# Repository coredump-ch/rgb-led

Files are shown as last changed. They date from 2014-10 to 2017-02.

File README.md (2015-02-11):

# RGB LED

An RGB LED board, originally developed in fall 2014 by coredump hackerspace in
Rapperswil, Switzerland for teaching kids (~10y) the basics of electronics.

## Version 1

The v1 consists of a potentiometer for each RGB color. The current is only
controlled by the potentiometers. Therefore not too many LEDs can be driven at
the same time.

In contrast to v2 the v1 is also missing a switch to turn on/off the power.

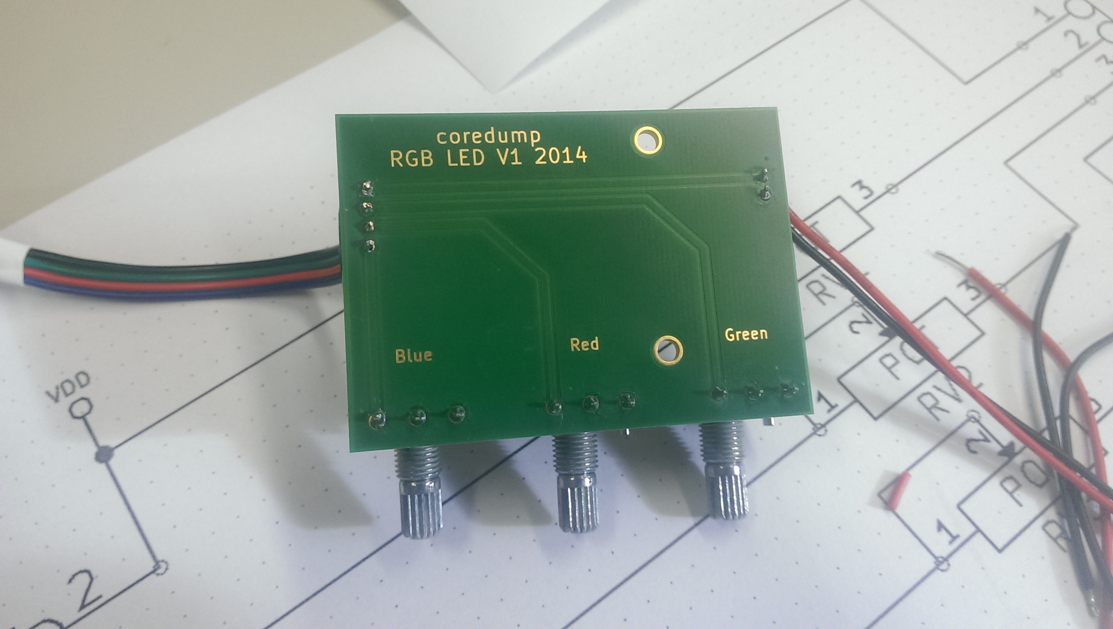
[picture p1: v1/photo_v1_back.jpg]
foto v1


## Version 2

The v2 is more advanced and uses an Arduino Nano as controller. The arduino
controls the RGB LEDs' brightness through PWM. The LEDs are switched with three
MOSFETs. This enables the control of more LEDs at the same time.

Project description is here: http://www.hackster.io/2460/arduino-controlled-rgb-led-strip

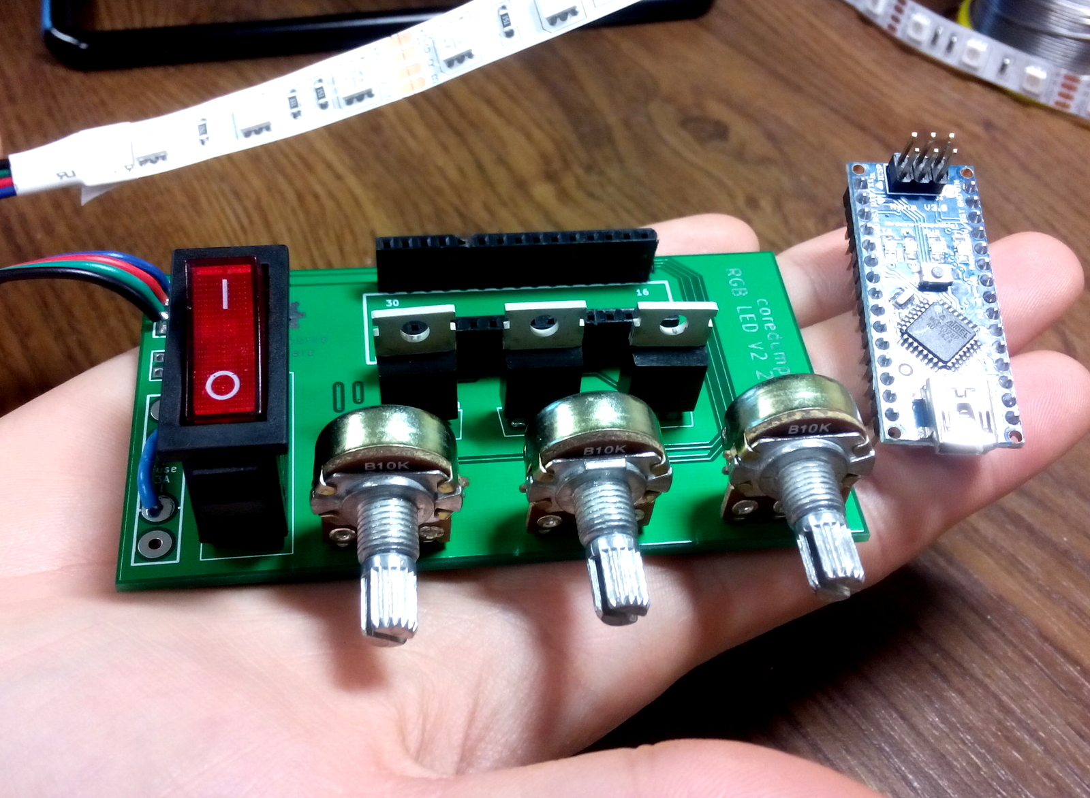
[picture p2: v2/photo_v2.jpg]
foto v2

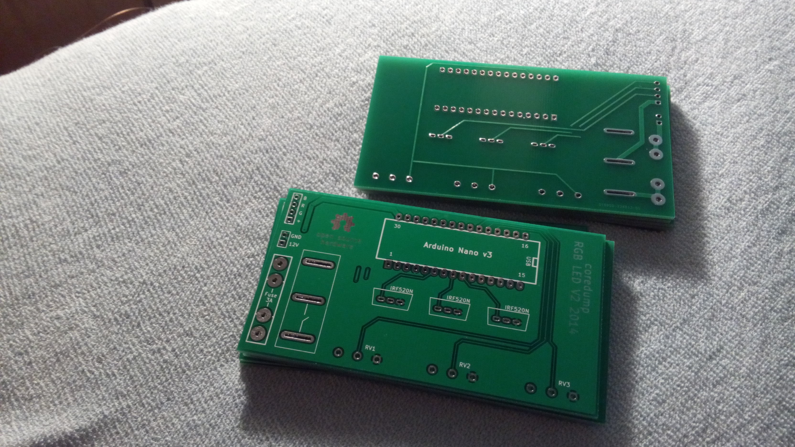
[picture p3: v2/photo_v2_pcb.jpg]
foto v2 pcb

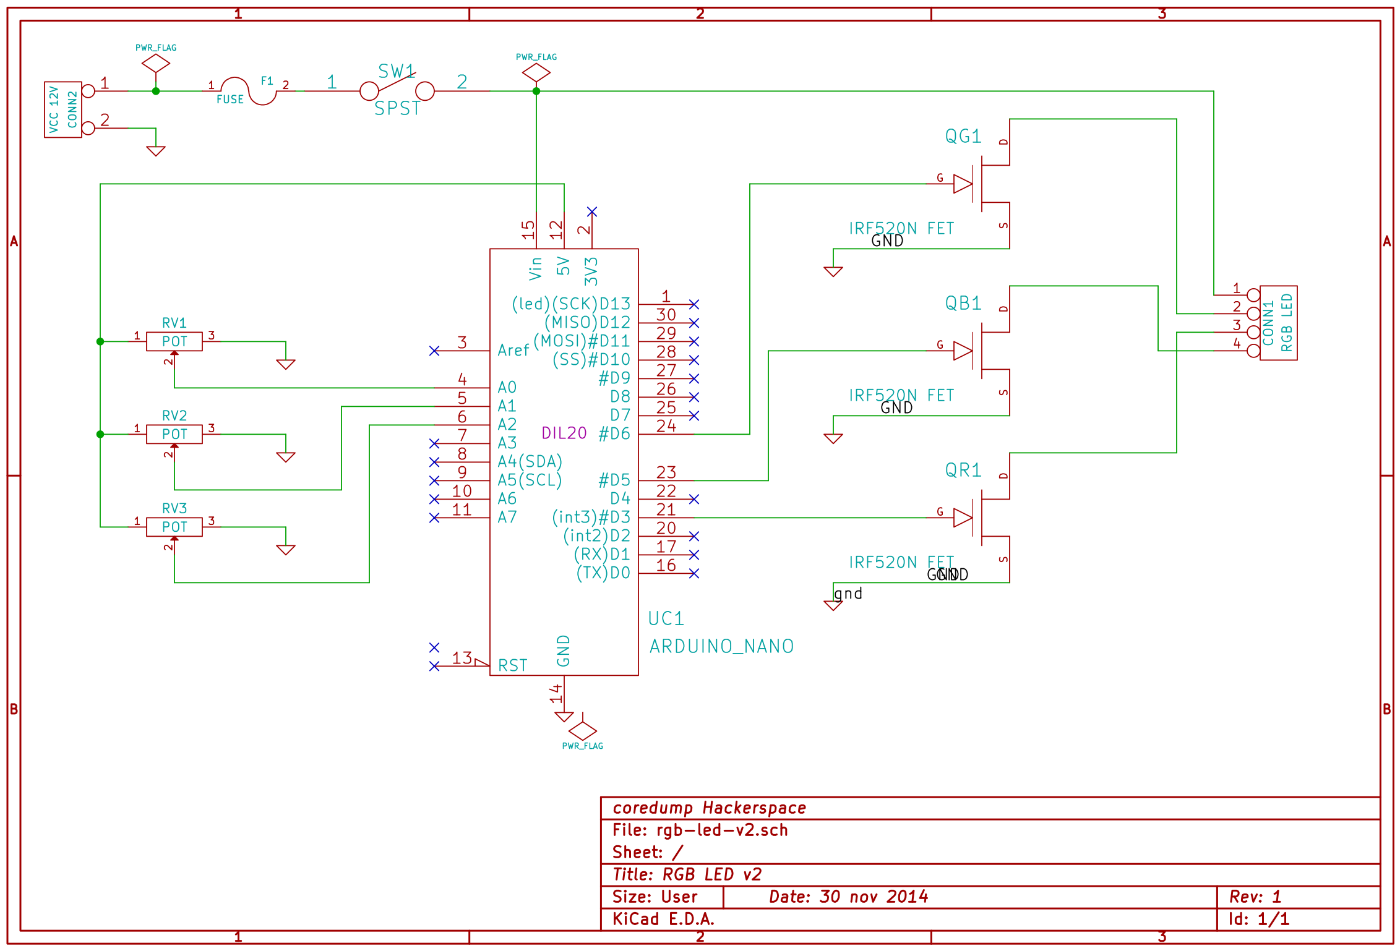
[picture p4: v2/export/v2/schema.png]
schema v2


## Licensing

See `LICENSE.md` file.

[v1-photo-back]: https://raw.githubusercontent.com/coredump-ch/rgb-led/master/v1/photo_v1_back.jpg
[v2-schema]: https://raw.githubusercontent.com/coredump-ch/rgb-led/master/v2/export/v2/schema.png
[v2-photo]: https://raw.githubusercontent.com/coredump-ch/rgb-led/master/v2/photo_v2.jpg
[v2-photo-pcb]: https://raw.githubusercontent.com/coredump-ch/rgb-led/master/v2/photo_v2_pcb.jpg

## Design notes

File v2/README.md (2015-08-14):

# Pinout

## LEDs

- Red: D3 / 1
- Green: D6 / 10
- Blue: D5 / 9

## Pots

- 1: A0 / 14
- 2: A1 / 15
- 3: A2 / 16

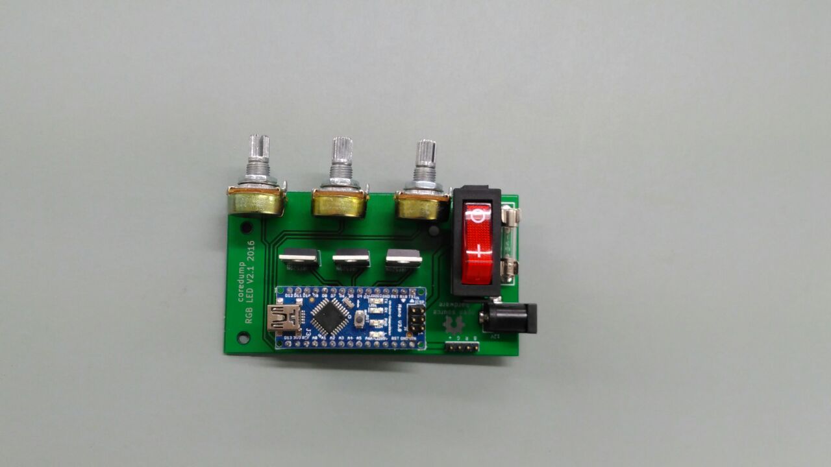
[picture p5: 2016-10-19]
v2/photo_v2.1_complete1.jpg

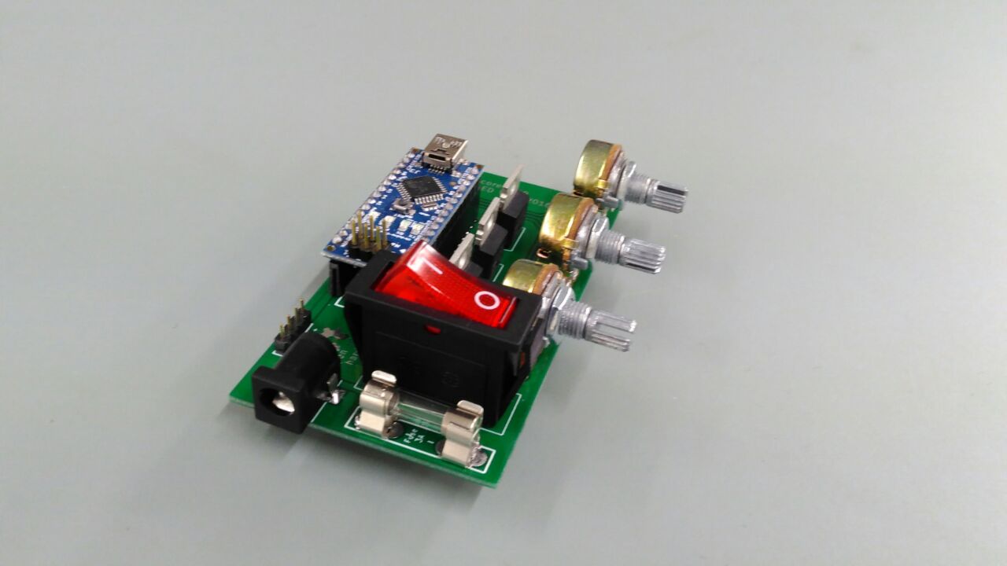
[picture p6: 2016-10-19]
v2/photo_v2.1_complete2.jpg

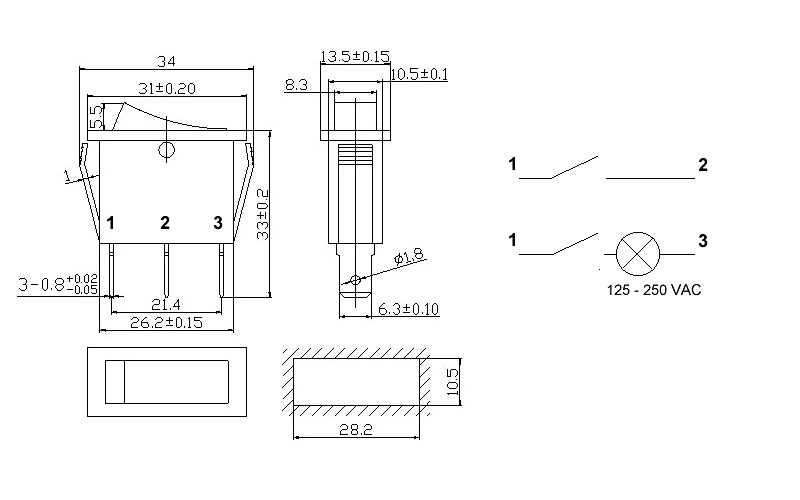
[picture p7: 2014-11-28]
kicad-library/kippschalter.gif

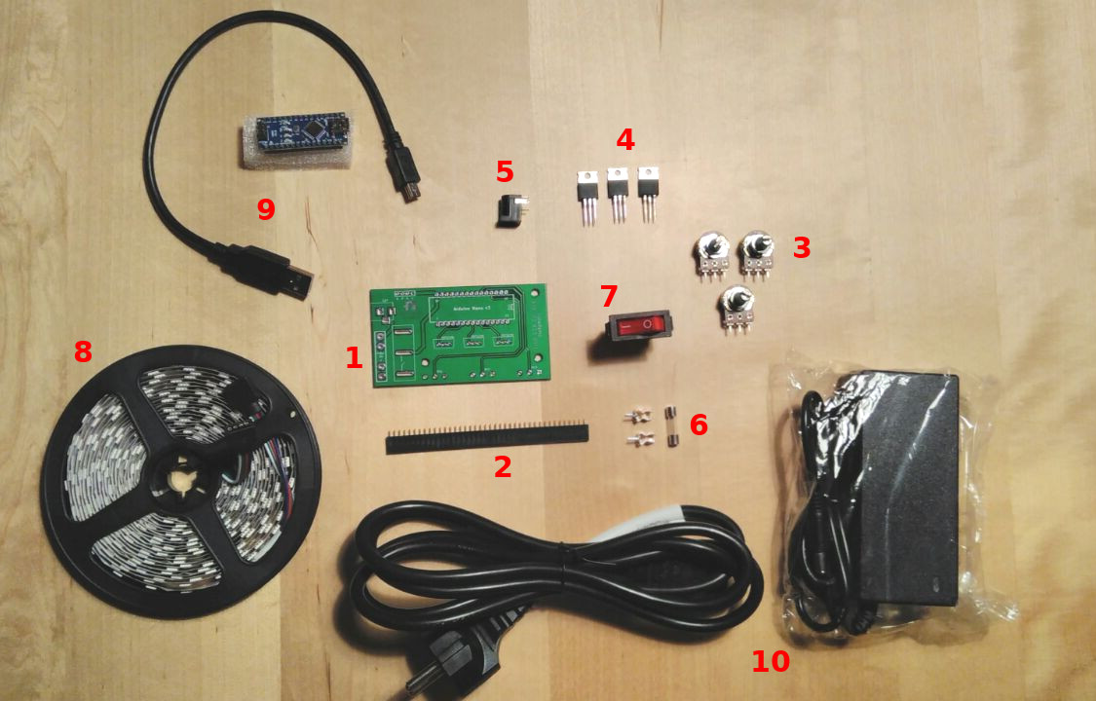
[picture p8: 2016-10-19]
v2/photo_v2.1_kit.jpg

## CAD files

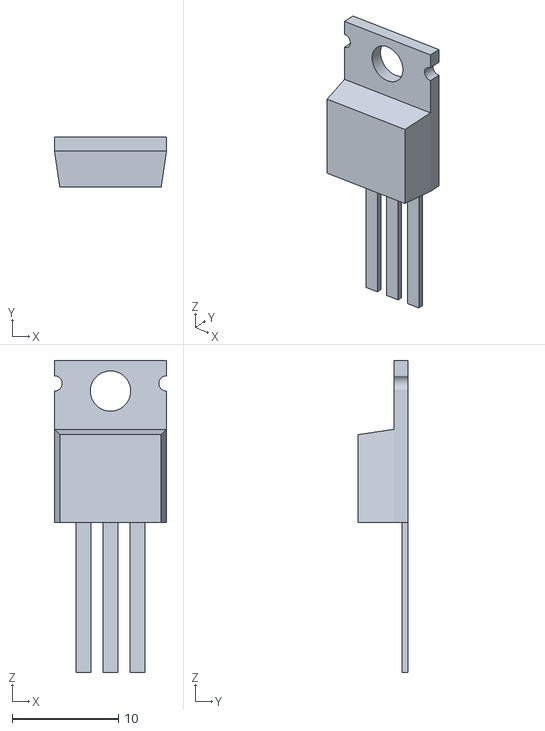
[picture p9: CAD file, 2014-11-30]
kicad-library/irf520n.fixed.stl
10.5 x 4.69 x 29.3

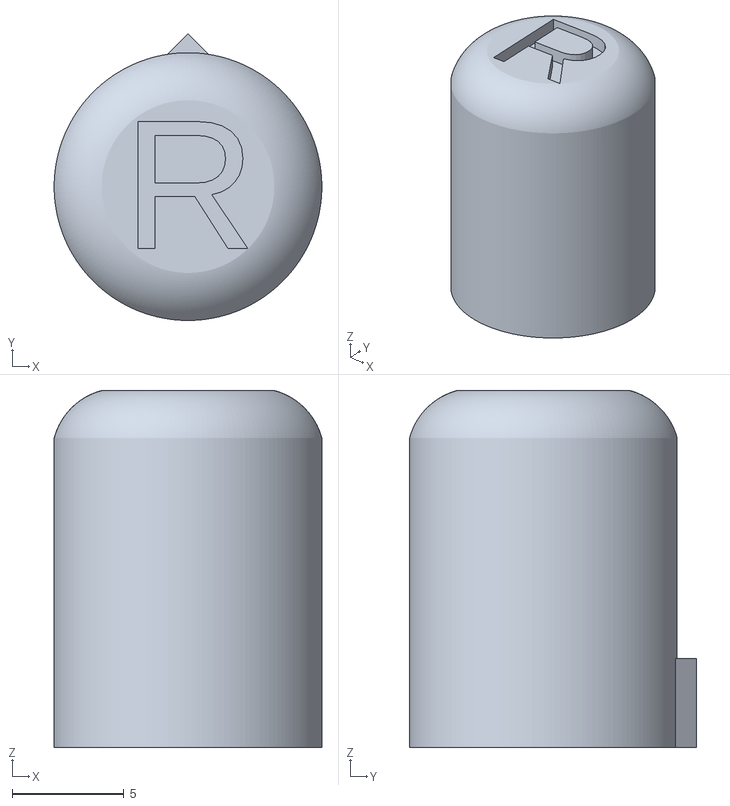
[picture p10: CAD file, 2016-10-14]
potknobs/knob-r-v3.stl
12.0 x 12.9 x 16.0

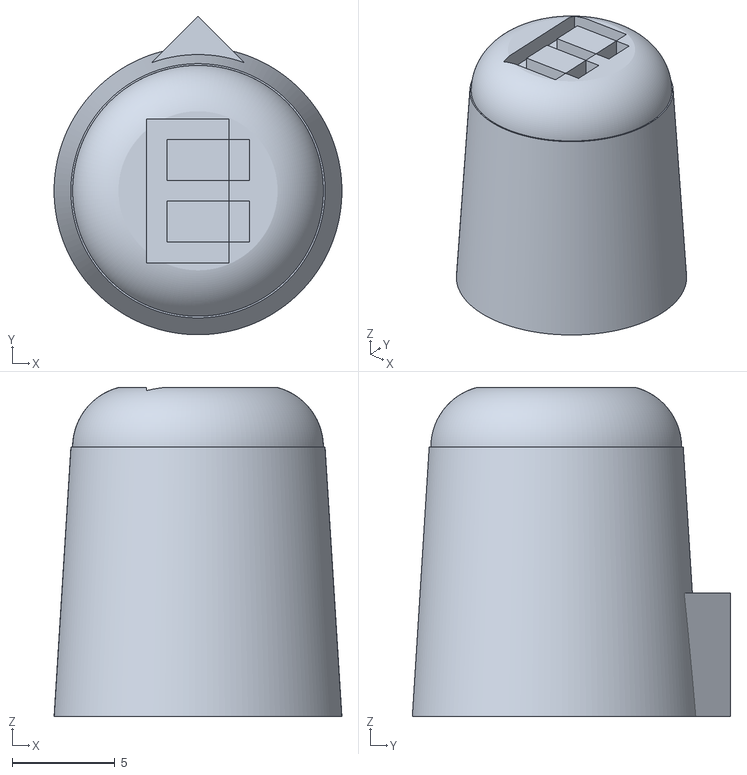
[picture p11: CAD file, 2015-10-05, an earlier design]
potknobs/knob-b-v2.stl
14.0 x 15.5 x 16.0

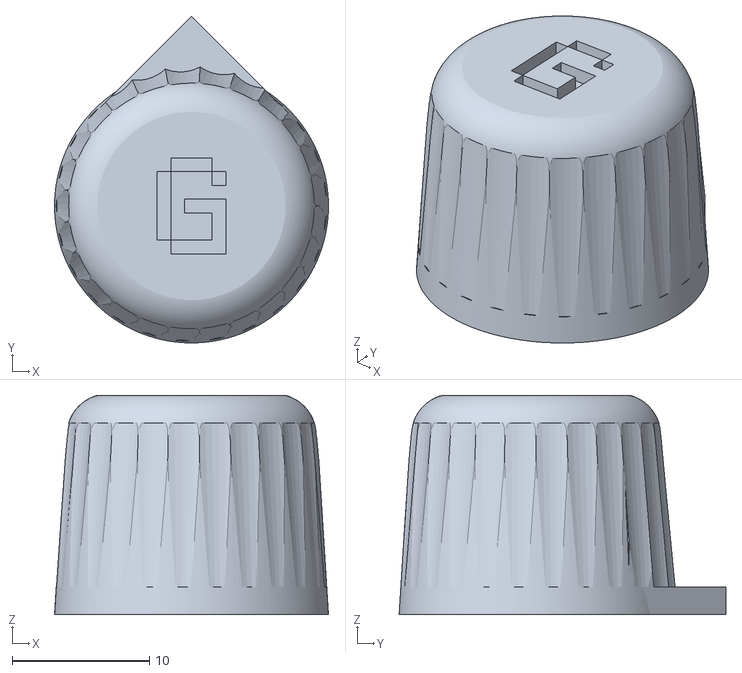
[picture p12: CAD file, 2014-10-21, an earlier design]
potknobs/knob-g.stl
20.0 x 23.9 x 16.0

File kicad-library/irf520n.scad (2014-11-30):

width = 10.54;
height2 = 15.24;
height1 = height2 - 6.47;
depth = 4.69;
indent = 0.5;
pin_length = 14.09;
metal_thickness = 1.32;

module metal() {
	small_circle_radius = 2.87 / 2 / 2;

	linear_extrude(height=metal_thickness) {
		difference() {
			square([10.54,height2]);
			translate([5.27,height2-2.87]) circle(3.78/2, $fn=200);
			translate([0,height2-2.87+small_circle_radius]) circle(small_circle_radius, $fn=200);
			translate([width,height2-2.87+small_circle_radius]) circle(small_circle_radius, $fn=200);
		};
	};
};

module casing() {
	polyhedron(
		points=[
			// Back
			[0,0,metal_thickness],[0,height1,metal_thickness],
			[width,height1,metal_thickness],[width,0,metal_thickness],
			// Front
			[0+indent,0,depth],[0+indent,height1-indent,depth],
			[width-indent,height1-indent,depth],[width-indent,0,depth]
		],
		faces=[[0,3,2,1],[4,5,6,7],[0,1,5,4],[1,2,6,5],[3,7,6,2],[0,4,7,3]]
	);
};

module pins() {
	pin_width = 1.4;
	center = (width / 2) - (pin_width / 2);
	distance = 2.54;

	translate([center-distance,-pin_length,0]) cube([pin_width,pin_length,0.55]);
	translate([center,-pin_length,0]) cube([pin_width,pin_length,0.55]);
	translate([center+distance,-pin_length,0]) cube([pin_width,pin_length,0.55]);
};

module everything() {
	union() {
		metal();
		casing();
		pins();
	};
};


rotate(a=[90,0,0]) everything();

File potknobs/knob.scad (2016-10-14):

/*

Parametric Potentiometer Knob Generator
version 2.0

2012 Steve Cooley
2014 Danilo Bargen

Parametric potentiometer knob generator by steve cooley is licensed under a
Creative Commons Attribution-NonCommercial-ShareAlike 3.0 Unported License.
Based on a work at sc-fa.com. Permissions beyond the scope of this license may
be available at http://sc-fa.com/blog/contact.

View terms of the license here:
http://creativecommons.org/licenses/by-nc-sa/3.0/


Version history
---------------

1.0 2012-03-?? initial release.
1.1 2012-04-12 fixed the arrow indicator code to be more robust and easier to adjust parameters for.
2.0 2014-09-17 updated the code
3.0 2016-10-14 replace custom text module with text() function and make knobs thinner


*/

//
//
// Physical attributes, basic
//
//

knob_radius_top = 6;
knob_radius_bottom = 6;
knob_height = 16;
knob_smoothness = 150;

shaft_radius = 3.16;
shaft_height = 13;
shaft_smoothness = 20;

shaft_is_flatted = false;
flat_size_adjustment = -0.0;
// you won't need to mess with this. less than 5 makes it disappear. you can, however,
// set the adjustment to be a negative decimal if you need a flat but not as big as the default. 
// go positive if you need a bigger flat
flat_size = 5 + flat_size_adjustment;

// some potentiometers need to have their knobs affixed with a set screw.
set_screw = false;
set_screw_radius = 1.5;
set_screw_depth = 9;
set_screw_height = 4;
quality_of_set_screw = 20;

//
// 
// Decorations
//
//

//
// top edge smoothing
// thanks to http://www.iheartrobotics.com/ for the articles!
//

smoothing = true;
smoothing_radius = 3;             // tweak on this one, how much smoothing to apply
smooth = 150;                     // tweak on this one, Number of facets of rounding cylinder

ct = -0.1;                        // circle translate? not sure.
circle_radius = knob_radius_top;  // just match the top edge radius
circle_height = 1;                // actually.. I don't know what this does.
pad = 0.2;                        // Padding to maintain manifold

top_letter = "R";

//
// directional indicators
//

// this is a corner edge of a cube sticking out of the cylinder at the bottom
// you can use it instead of the arrow shaped cutout in the top if you like. Or both.

pointy_external_indicator = true;
pointy_external_indicator_height = 4;
pointy_external_indicator_pokey_outey_ness = 0.05; // 
pokey_outey_value = pointy_external_indicator_pokey_outey_ness - 1 - pad;
pokey_outey = [pokey_outey_value, pokey_outey_value,0];

// there's an arrow shaped hole you can have. There aren't a lot of controls for this.
// please feel free to improve on this script here.

arrow_indicator = false;
arrow_indicator_scale = 1.3;
arrow_indicator_translate = [0,1,16];
arrow_scale_head = 1.5;
arrow_scale_shaft = 1;

//
// indentations
//

// for spherical indentations, set the quantity, quality, size, and adjust the placement
indentations_sphere = false;
sphere_number_of_indentations = 12;
sphere_quality_of_indentations = 4;
size_of_sphere_indentations = 4;
// the first number in this set moves the spheres in or out. smaller is closer to the middle
// the second number in this set moves the spheres left or right
// the third number in this set moves the speheres up or down
translation_of_sphere_indentations = [10,0,15];
// in case you are using an odd number of indentations, you way want to adjust the starting angle
// so that they align to the front or set screw locations.
sphere_starting_rotation = 90;

// for cylinder indentations, set quantity, quality, radius, height, and placement
indentations_cylinder = false;
cylinder_number_of_indentations = 25;
cylinder_quality_of_indentations = 50;
radius_of_cylinder_indentations_top = 4;
radius_of_cylinder_indentations_bottom = 3;
height_of_cylinder_indentations = 12;
translation_of_cylinder_indentations = [0,8,-8];
cylinder_starting_rotation = -33.3;

// these are some setup variables... you probably won't need to mess with them.
negative_knob_radius = knob_radius_bottom*-1;


inner_bar = true;
inner_bar_thickness = 1;
inner_bar_height = shaft_height - 3;
inner_bar_length = shaft_radius * 2 + 2;


// this is the main module. It calls the submodules.
make_the_knob();

module make_the_knob()
{
union() {
  difference() {
  difference()
    {
    difference()
      {
    
      difference() 
        {
        difference() 
          {
          
          union()
            {
            
            difference()
              {
              // main cylinder
              cylinder(r1=knob_radius_bottom,r2=knob_radius_top,h=knob_height, $fn=knob_smoothness);
              
              smoothing();        
    
              }
        
            external_direction_indicator();  

            }
          shaft_hole();
          }
          
        set_screw_hole();
        }
      
      arrow_indicator();
      indentations();
    }
  }
  letter();
  }
   inner_bar();
}
}

module smoothing() {
  // smoothing the top
  if(smoothing == true) {    
    translate([0,0,knob_height])
    rotate([180,0,0])
    difference() {
      rotate_extrude(convexity=10,  $fn = smooth)
      translate([circle_radius-ct-smoothing_radius+pad,ct-pad,0])
      square(smoothing_radius+pad,smoothing_radius+pad);

      rotate_extrude(convexity=10,  $fn = smooth)
      translate([circle_radius-ct-smoothing_radius,ct+smoothing_radius,0])
      circle(r=smoothing_radius,$fn=smooth);
      }  
  }
}

module external_direction_indicator() {
  if(pointy_external_indicator == true) {
    // outer pointy indicator
    rotate([0,0,45])
      translate(pokey_outey)
      // cube size of 8 minimum to point out
      cube(size=[knob_radius_bottom,knob_radius_bottom,pointy_external_indicator_height],center=false);
  }
}

module shaft_hole() {
        // shaft hole
        difference()
          {
          
          // round shaft hole
          translate([ 0, 0, -1 ]) 
          cylinder(r=shaft_radius,h=shaft_height, $fn=shaft_smoothness);
          
          if(shaft_is_flatted == true)
            {
            // D shaft shape for shaft cutout
            rotate( [0,0,90]) 
            translate([-7.5,-5,0]) 
            cube(size=[flat_size,10,13],center=false);
            }
          }
}


module set_screw_hole() {

      if(set_screw == true)
        {
        // set screw hole
        rotate ([90,0,0])
        translate([ 0, set_screw_height, 1 ])
        cylinder(r=set_screw_radius,h=set_screw_depth, $fn=quality_of_set_screw);
        }
}

module arrow_indicator() {
    if(arrow_indicator == true)
      {
      translate(arrow_indicator_translate)
      // begin arrow top cutout
      // translate([(knob_radius/2),knob_height,knob_height])
      rotate([90,0,45])
      scale([arrow_indicator_scale*.3,arrow_indicator_scale*.3,arrow_indicator_scale*.3])
      union()
        {        
        rotate([90,45,0])
        scale([arrow_scale_head,arrow_scale_head,1])
        cylinder(r=8, h=10, $fn=3, center=true);
        rotate([90,45,0])
        translate([-10,0,0])
        scale([arrow_scale_shaft,arrow_scale_shaft,1])
        cube(size=[15,10,10],center=true);
        }
      }
}

module indentations() {

if(indentations_sphere == true)
      {
      for (z = [0:sphere_number_of_indentations]) 
        {
        rotate([0,0,sphere_starting_rotation+((360/sphere_number_of_indentations)*z)])
        translate(translation_of_sphere_indentations)
        sphere(size_of_sphere_indentations, $fn=sphere_quality_of_indentations); 
        }
      }
if(indentations_cylinder == true)
      {
      for (z = [0:cylinder_number_of_indentations]) 
        {
        rotate([0,0,cylinder_starting_rotation+((360/cylinder_number_of_indentations)*z)])
        
        translate([negative_knob_radius,0,knob_height])
        translate(translation_of_cylinder_indentations)
        cylinder(r1=radius_of_cylinder_indentations_bottom, r2=radius_of_cylinder_indentations_top, h=height_of_cylinder_indentations, center=true, $fn=cylinder_quality_of_indentations); 
        }
      }
    }

module inner_bar() {
  if (inner_bar == true) {
    translate([-inner_bar_length/2,-inner_bar_thickness/2,shaft_height-inner_bar_height]) {
      cube([inner_bar_length,inner_bar_thickness,inner_bar_height]);
    }
  }
}

module letter() {
  translate([0,0,knob_height-0.7999])
    linear_extrude(0.8)
    text(top_letter, size=6, valign="center", halign="center");
}

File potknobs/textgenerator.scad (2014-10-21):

/*

OpenSCAD 3D Text Generator

http://www.thingiverse.com/thing:59817/

CC BY-SA Phil Greenland.
https://creativecommons.org/licenses/by-sa/3.0/

*/

//Draw text
scale([4,4,4]) drawtext("Hello World!");

//Draw character set
//scale([2,2,2]) drawtext(" !\"#$%&'()*+,-./0123456789:;<=>?@ABCDEFGHIJKLMNOPQRSTUVWXYZ[\\]^_`abcdefghijklmnopqrstuvwxyz{|}");

module drawtext(text) {
	//Characters
	chars = " !\"#$%&'()*+,-./0123456789:;<=>?@ABCDEFGHIJKLMNOPQRSTUVWXYZ[\\]^_`abcdefghijklmnopqrstuvwxyz{|}";

	//Chracter table defining 5x7 characters
	//Adapted from: http://www.geocities.com/dinceraydin/djlcdsim/chartable.js
	char_table = [ [ 0, 0, 0, 0, 0, 0, 0],
                  [ 4, 0, 4, 4, 4, 4, 4],
                  [ 0, 0, 0, 0,10,10,10],
                  [10,10,31,10,31,10,10],
                  [ 4,30, 5,14,20,15, 4],
                  [ 3,19, 8, 4, 2,25,24],
                  [13,18,21, 8,20,18,12],
                  [ 0, 0, 0, 0, 8, 4,12],
                  [ 2, 4, 8, 8, 8, 4, 2],
                  [ 8, 4, 2, 2, 2, 4, 8],
                  [ 0, 4,21,14,21, 4, 0],
                  [ 0, 4, 4,31, 4, 4, 0],
                  [ 8, 4,12, 0, 0, 0, 0],
                  [ 0, 0, 0,31, 0, 0, 0],
                  [12,12, 0, 0, 0, 0, 0],
                  [ 0,16, 8, 4, 2, 1, 0],
                  [14,17,25,21,19,17,14],
                  [14, 4, 4, 4, 4,12, 4],
                  [31, 8, 4, 2, 1,17,14],
                  [14,17, 1, 2, 4, 2,31],
                  [ 2, 2,31,18,10, 6, 2],
                  [14,17, 1, 1,30,16,31],
                  [14,17,17,30,16, 8, 6],
                  [ 8, 8, 8, 4, 2, 1,31],
                  [14,17,17,14,17,17,14],
                  [12, 2, 1,15,17,17,14],
                  [ 0,12,12, 0,12,12, 0],
                  [ 8, 4,12, 0,12,12, 0],
                  [ 2, 4, 8,16, 8, 4, 2],
                  [ 0, 0,31, 0,31, 0, 0],
                  [16, 8, 4, 2, 4, 8,16],
                  [ 4, 0, 4, 2, 1,17,14],
                  [14,21,21,13, 1,17,14],
                  [17,17,31,17,17,17,14],
                  [30,17,17,30,17,17,30],
                  [14,17,16,16,16,17,14],
                  [30,17,17,17,17,17,30],
                  [31,16,16,30,16,16,31],
                  [16,16,16,30,16,16,31],
                  [15,17,17,23,16,17,14],
                  [17,17,17,31,17,17,17],
                  [14, 4, 4, 4, 4, 4,14],
                  [12,18, 2, 2, 2, 2, 7],
                  [17,18,20,24,20,18,17],
                  [31,16,16,16,16,16,16],
                  [17,17,17,21,21,27,17],
                  [17,17,19,21,25,17,17],
                  [14,17,17,17,17,17,14],
                  [16,16,16,30,17,17,30],
                  [13,18,21,17,17,17,14],
                  [17,18,20,30,17,17,30],
                  [30, 1, 1,14,16,16,15],
                  [ 4, 4, 4, 4, 4, 4,31],
                  [14,17,17,17,17,17,17],
                  [ 4,10,17,17,17,17,17],
                  [10,21,21,21,17,17,17],
                  [17,17,10, 4,10,17,17],
                  [ 4, 4, 4,10,17,17,17],
                  [31,16, 8, 4, 2, 1,31],
                  [14, 8, 8, 8, 8, 8,14],
                  [ 0, 1, 2, 4, 8,16, 0],
                  [14, 2, 2, 2, 2, 2,14],
                  [ 0, 0, 0, 0,17,10, 4],
                  [31, 0, 0, 0, 0, 0, 0],
                  [ 0, 0, 0, 0, 2, 4, 8],
                  [15,17,15, 1,14, 0, 0],
                  [30,17,17,25,22,16,16],
                  [14,17,16,16,14, 0, 0],
                  [15,17,17,19,13, 1, 1],
                  [14,16,31,17,14, 0, 0],
                  [ 8, 8, 8,28, 8, 9, 6],
                  [14, 1,15,17,15, 0, 0],
                  [17,17,17,25,22,16,16],
                  [14, 4, 4, 4,12, 0, 4],
                  [12,18, 2, 2, 2, 6, 2],
                  [18,20,24,20,18,16,16],
                  [14, 4, 4, 4, 4, 4,12],
                  [17,17,21,21,26, 0, 0],
                  [17,17,17,25,22, 0, 0],
                  [14,17,17,17,14, 0, 0],
                  [16,16,30,17,30, 0, 0],
                  [ 1, 1,15,19,13, 0, 0],
                  [16,16,16,25,22, 0, 0],
                  [30, 1,14,16,15, 0, 0],
                  [ 6, 9, 8, 8,28, 8, 8],
                  [13,19,17,17,17, 0, 0],
                  [ 4,10,17,17,17, 0, 0],
                  [10,21,21,17,17, 0, 0],
                  [17,10, 4,10,17, 0, 0],
                  [14, 1,15,17,17, 0, 0],
                  [31, 8, 4, 2,31, 0, 0],
                  [ 2, 4, 4, 8, 4, 4, 2],
                  [ 4, 4, 4, 4, 4, 4, 4],
                  [ 8, 4, 4, 2, 4, 4, 8] ];

	//Binary decode table
	dec_table = [ "00000", "00001", "00010", "00011", "00100", "00101",
  	            "00110", "00111", "01000", "01001", "01010", "01011",
  	            "01100", "01101", "01110", "01111", "10000", "10001",
  	            "10010", "10011", "10100", "10101", "10110", "10111",
	            "11000", "11001", "11010", "11011", "11100", "11101",
	            "11110", "11111" ];

	//Process string one character at a time
	for(itext = [0:len(text)-1]) {
		//Convert character to index
		assign(ichar = search(text[itext],chars,1)[0]) {
			//Decode character - rows
			for(irow = [0:6]) {
				assign(val = dec_table[char_table[ichar][irow]]) {
					//Decode character - cols
					for(icol = [0:4]) {
						assign(bit = search(val[icol],"01",1)[0]) {
							if(bit) {
								//Output cube
								translate([icol + (6*itext), irow, 0])
									cube([1.0001,1.0001,1]);
							}
						}
					}
				}
			}
		}
	}
}

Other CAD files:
kicad-library/irf520n.stl
potknobs/knob-g-v3.stl
potknobs/knob-b-v3.stl
potknobs/knob-neutral-v3.stl
potknobs/knob-g-v2.stl
potknobs/knob-r-v2.stl
potknobs/knob-r.stl
potknobs/knob-b.stl

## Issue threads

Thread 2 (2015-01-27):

Add buttons and/or rotary encoder

dbrgn, 2015-01-27:
They can be used to step through different effects.

dbrgn, 2015-01-27:
They can be used to step through different effects.

dbrgn, 2015-08-24:
I think the best solution would be to add a single rotary encoder.

dns2utf8, 2016-03-07:
I would prefere a rotay encoder and two buttons.

dbrgn, 2016-03-07:
The other option is an ESP8266 and an app :)

dbrgn, 2016-08-11:
Something like this? http://mikroshop.ch/?gruppe=10&artikel=44 Has an integrated push-button.

Closed 2017-02-19.

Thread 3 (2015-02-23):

Mounting holes

dbrgn, 2015-02-23:

schmijos, 2015-02-24:
?

dbrgn, 2015-02-24:
Das PCB (v2.1) braucht noch mounting holes :) So wie hier, einfach professioneller:

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

schmijos, 2015-02-24:
Achso :-)

rnestler, 2015-02-24:
Wie geil :smile:

rnestler, 2016-09-21:
closed with #11

Closed 2016-09-21.

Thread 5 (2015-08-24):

Add power switch to v1 PCB

rnestler, 2015-08-24:
The simple v1 PCB should have a power switch nonetheless.

dbrgn, 2016-08-11:
Can probably be closed now right?

Closed 2016-08-11.

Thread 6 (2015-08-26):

v3: Add breakout pins

dbrgn, 2015-08-26:
That would be nice, wouldn't it? :) Not sure if it's easily possible with this PCB though.

dbrgn, 2016-08-11:
This would be nice-to-have for the v2.1 board.

Closed 2017-02-19.

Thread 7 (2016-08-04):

Holes for switch are a bit narrow

dbrgn, 2016-08-04:
Make them a tiny bit wider.

rnestler, 2016-08-24:
In x or y direction or both?

dbrgn, 2016-08-31:
Width (the shorter of the two axes). The length is OK.

Closed 2016-09-15.

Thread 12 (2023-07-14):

Arduino fried

Omega1806, 2023-07-14:
Hi, i tried the project.
Did the PCB's at pcbway, and started the project.
I just wanted the classic, potentiometer RGB controller.
First try, put the program with effects on the arduino.
After starting it, i couldn't connect to the board any more, or upload any code.
Secound try, bought another Arduino.
Test no.1: with 1m LED strip and 12v 2A power supply, SUCCESS! it worked.
Test no 2: swaped the 1m strip with 4m, same power supply. Arduino started smoking. Burned the 5v regulator on it.
Test no 3: swaped the Arduino board with a new one. after starting i got green colour flashing + no reaction on the potentiometers + Arduino started to heat up.

What could be the issue? i'm kind of runnin' out of ideas and money for this project (getting to expensive).

Please help!

Thanks 😄

PS: tested every soldering for shortcircuits. the tests from the secound arduino were made with a new pcb. and new components.

dbrgn, 2023-07-16:
Are you using the same components as in our v2 schema here? https://raw.githubusercontent.com/coredump-ch/rgb-led/master/v2/export/v2/schema.png (i.e. MOSFETs and not transistors, and an appropriate power supply and fuse?)

Omega1806, 2023-07-17:
Hi, Thanks for the answer!
The only thing that was different was that i didn't have a 6A power supply, just a 2A power supply. Wich worked just fine until i tried the 4m LED strip...After that the 5V regulator in the Arduino started smoking.
That i might fried it with the "too small power supply", i don't argue. What i don't understand is why doesn't it work with another Arduino. Are there other components fried? I messured the mosfets, everything seems fine.

dbrgn, 2023-07-17:
I don't quite understand how it could fry the Arduino. The LED strips are powered directly by the power supply, and the Arduino simply switches the MOSFETs on and off.

The only thing I could imagine based on the schematic is that the LED strips could try to source current from the Arduino's VIn pin if the power supply does not provide enough power. However, I assume that the Arduino prevents that.

(Maybe @rnestler has another idea...)

Omega1806, 2023-07-17:
the problem is why isn't it working after swiching the arduino?
i mean before switching the 1m strip with the 4m one, everything worked fine...
This is my third try with the project. At the first try, i loaded the program with effects, but i wanted just the simple one with the potentiometers, but i couldn't load any program on the Arduino, comunication error.
bought everything for the second try, worked just fine before i switched the 1m strip with the 4m one.
Now i buy a 6A power supply, new arduino, new mosfets, new potentiometers, everything, and try again...

Ps: this is for my son, he is 4 years old, and i have done a plexiglass, wallmounted "lego ninjago" sign, wich i planned to light up with LED strip, wich he can adjust via potentiometers, so he can learn to mix colours.

rnestler, 2023-07-20:
If the LEDs draw so much current, that the voltage of the 2A supply drops *below* 5V, current may start to flow in reverse for a short period. Then the Arduino may reset and thus turning the LEDs off, which will stabilize the the voltage again, but then will immediately drop again since the Arduino turns the LEDs on again. (This would explain the color flashing)

This oscillating may then break the power supply of the Arduino.

But this is a very hand wavy explanation :wink:

rnestler, 2023-07-20:
The only protection the board has is the fuse, which of course needs to be rated *below* the maximum current the power-supply can deliver, since otherwise it is useless.

Theoretically one could add a software monitoring of the 12V supply and go in a fail state if the voltage ever drops below 10V or something (but this is hard to achieve, since measuring the voltage that powers your device is hard and it would also need to react extremely fast to handle a quasi short circuit from too many LEDs)

dbrgn, 2023-07-20:
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

Ah yeah, that makes sense!

Omega1806, 2023-07-21:
Hi guys, thank you all for the feedback!
The LED strip says on the specs that it consumes 14,5 W per meter. I connected 4m.

I will try again next week with a new arduino and a 5-6A power supply and get back to you with the results.

Have a nice weekend!!

rnestler, 2023-07-21:
>  The LED strip says on the specs that it consumes 14,5 W per meter. I connected 4m.

With a Voltage of 12V this gives you 4.83A: `(14.5W/m * 4m) /12V = 4.833A`. So a 5-6A power supply should be sufficient.

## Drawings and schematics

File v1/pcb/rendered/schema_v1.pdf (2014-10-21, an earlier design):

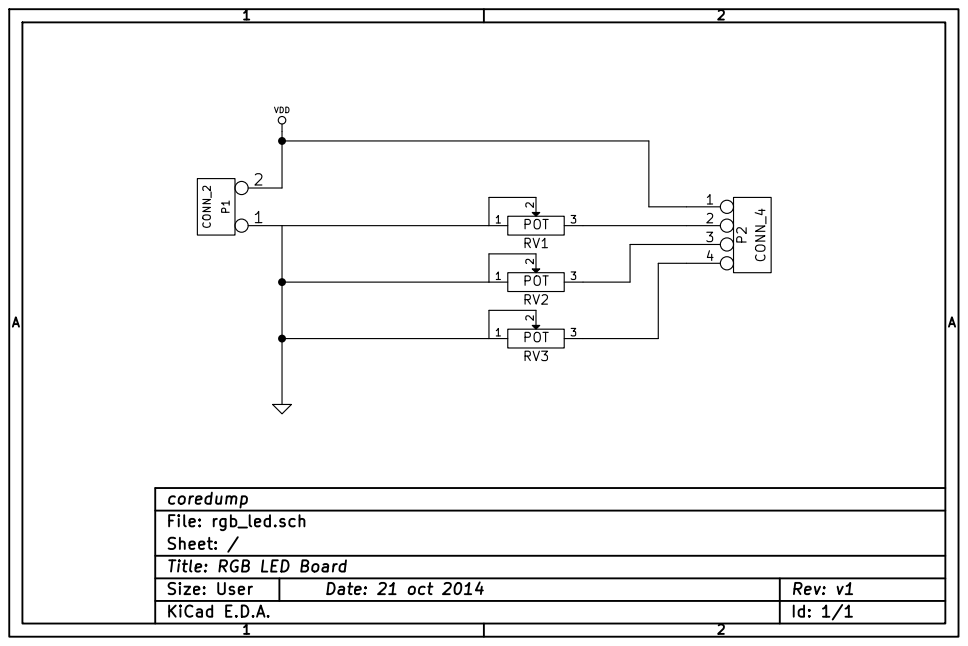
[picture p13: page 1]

coredump
File: rgb_led.sch
Sheet: /
Title: RGB LED Board

Size: User | Rev: v1

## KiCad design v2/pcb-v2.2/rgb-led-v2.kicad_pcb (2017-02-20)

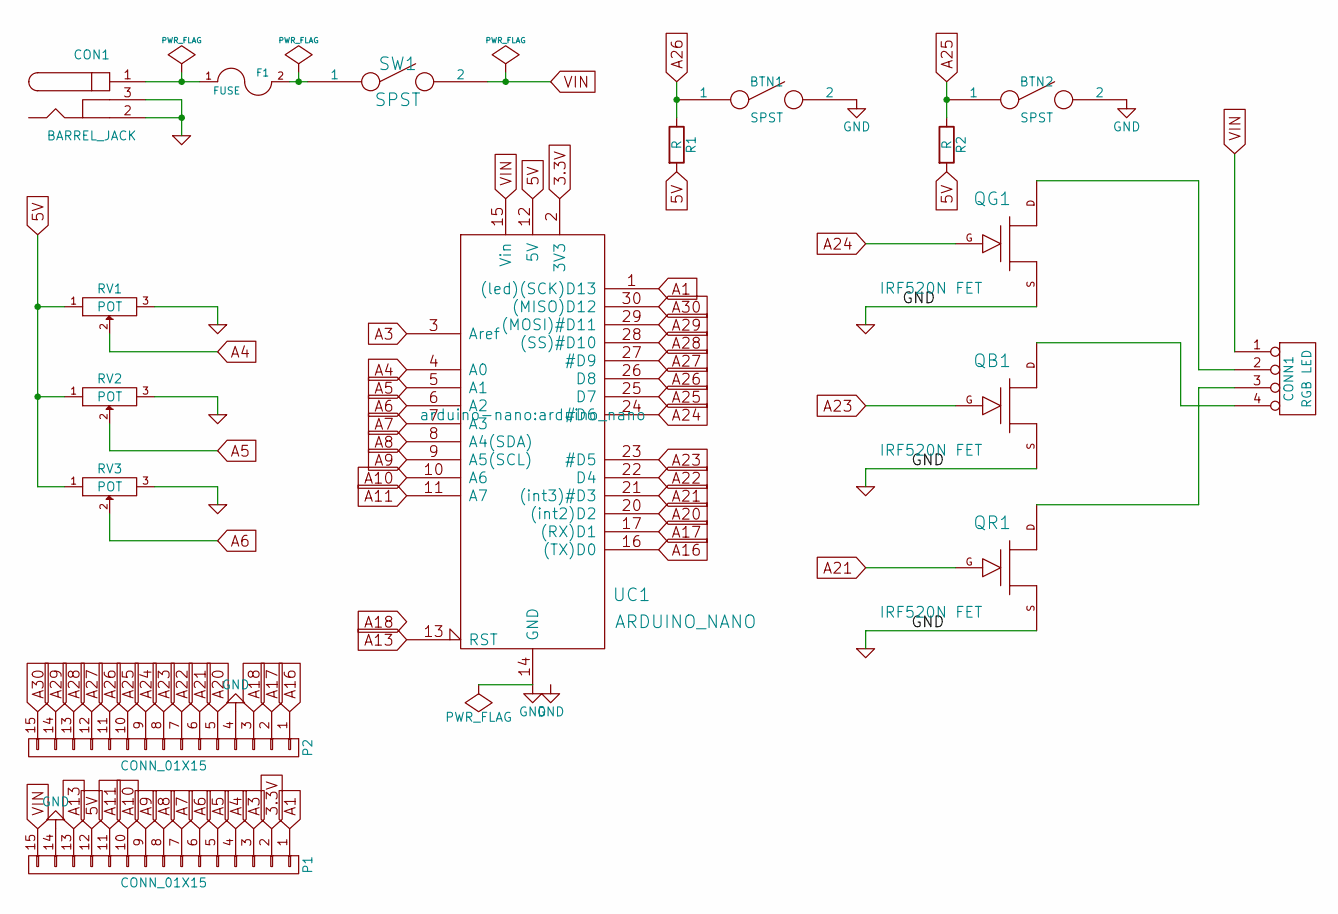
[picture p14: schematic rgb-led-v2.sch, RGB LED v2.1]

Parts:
BTN1, BTN2: SPST; PUSHBUTTON_TS044S
CON1: BARREL_JACK
CONN1: RGB LED; PIN_ARRAY_4x1_THICK
F1: FUSE; KCD3
P1, P2: CONN_01X15; Pin_Header_Straight_1x15_Pitch2.54mm
QB1: IRF520N FET; IRF520N
QG1: IRF520N FET; IRF520N
QR1: IRF520N FET; IRF520N
R1, R2: R; R_Axial_DIN0207_L6.3mm_D2.5mm_P10.16mm_Horizontal
RV1, RV2, RV3: POT; POT_3
SW1: SPST; Switch_SS-12F46
UC1: ARDUINO_NANO; arduino_nano

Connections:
3.3V: P1.2, UC1.2 (3V3)
5V: P1.12, R1.2, R2.2, RV1.1, RV2.1, RV3.1, UC1.12 (5V)
A1: P1.1, UC1.1 ((led)(SCK)D13)
A3: P1.3, UC1.3 (Aref)
A4: P1.4, RV1.2, UC1.4 (A0)
A5: P1.5, RV2.2, UC1.5 (A1)
A6: P1.6, RV3.2, UC1.6 (A2)
A7: P1.7, UC1.7 (A3)
A8: P1.8, UC1.8 (A4(SDA))
A9: P1.9, UC1.9 (A5(SCL))
A10: P1.10, UC1.10 (A6)
A11: P1.11, UC1.11 (A7)
A13: P1.13, UC1.13 (RST)
A16: P2.1, UC1.16 ((TX)D0)
A17: P2.2, UC1.17 ((RX)D1)
A18: P2.3, UC1.18 (RST)
A20: P2.5, UC1.20 ((int2)D2)
A21: P2.6, QR1.G, UC1.21 ((int3)#D3)
A22: P2.7, UC1.22 (D4)
A23: P2.8, QB1.G, UC1.23 (#D5)
A24: P2.9, QG1.G, UC1.24 (#D6)
A25: BTN2.1, P2.10, R2.1, UC1.25 (D7)
A26: BTN1.1, P2.11, R1.1, UC1.26 (D8)
A27: P2.12, UC1.27 (#D9)
A28: P2.13, UC1.28 ((SS)#D10)
A29: P2.14, UC1.29 ((MOSI)#D11)
A30: P2.15, UC1.30 ((MISO)D12)
GND: BTN1.2, BTN2.2, CON1.2, CON1.3, P1.14, P2.4, QB1.S, QG1.S, QR1.S, RV1.3, RV2.3, RV3.3, UC1.14 (GND), UC1.19 (GND)
unnamed: CON1.1, F1.1
unnamed: CONN1.2, QG1.D
unnamed: CONN1.3, QR1.D
unnamed: CONN1.4, QB1.D
unnamed: F1.2, SW1.1
VIN: CONN1.1, P1.15, SW1.2, UC1.15 (Vin)

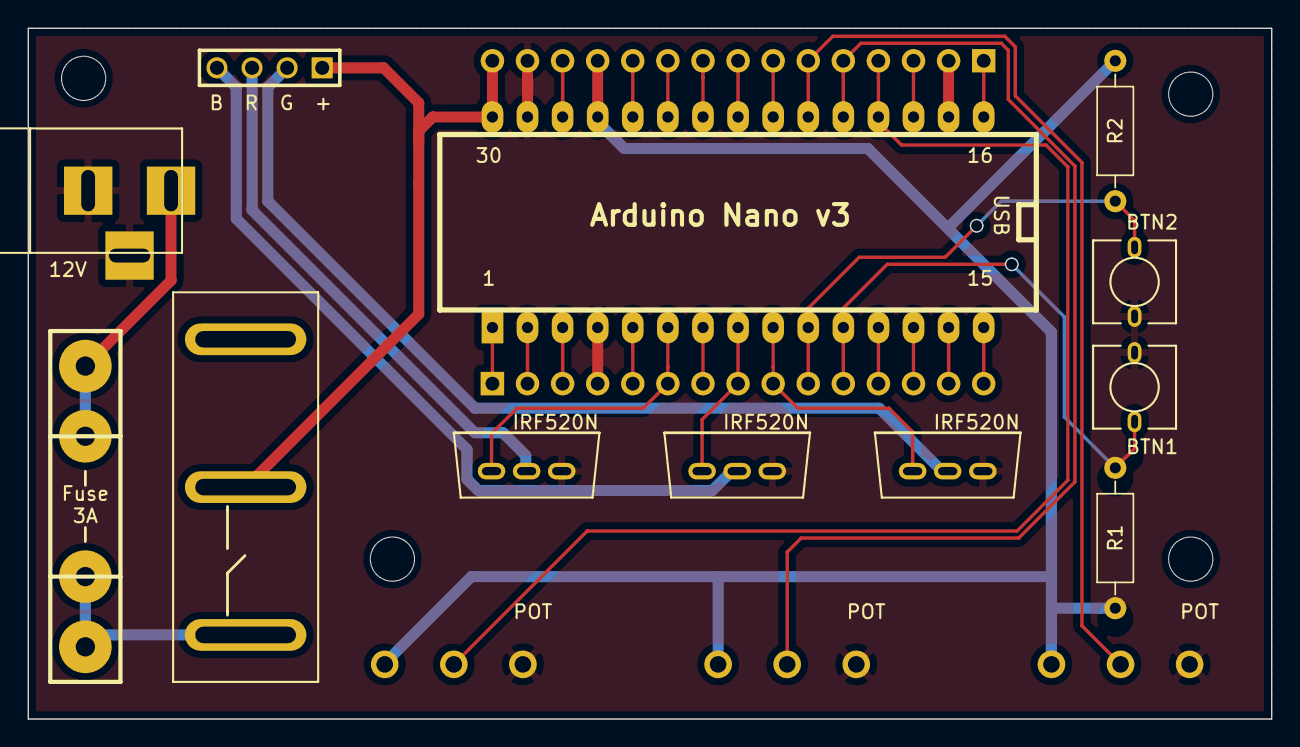
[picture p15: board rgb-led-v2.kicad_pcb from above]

Board: 2 copper layers, 90.0 x 50.0 mm, 17 parts (0 on the bottom side), 34 nets.

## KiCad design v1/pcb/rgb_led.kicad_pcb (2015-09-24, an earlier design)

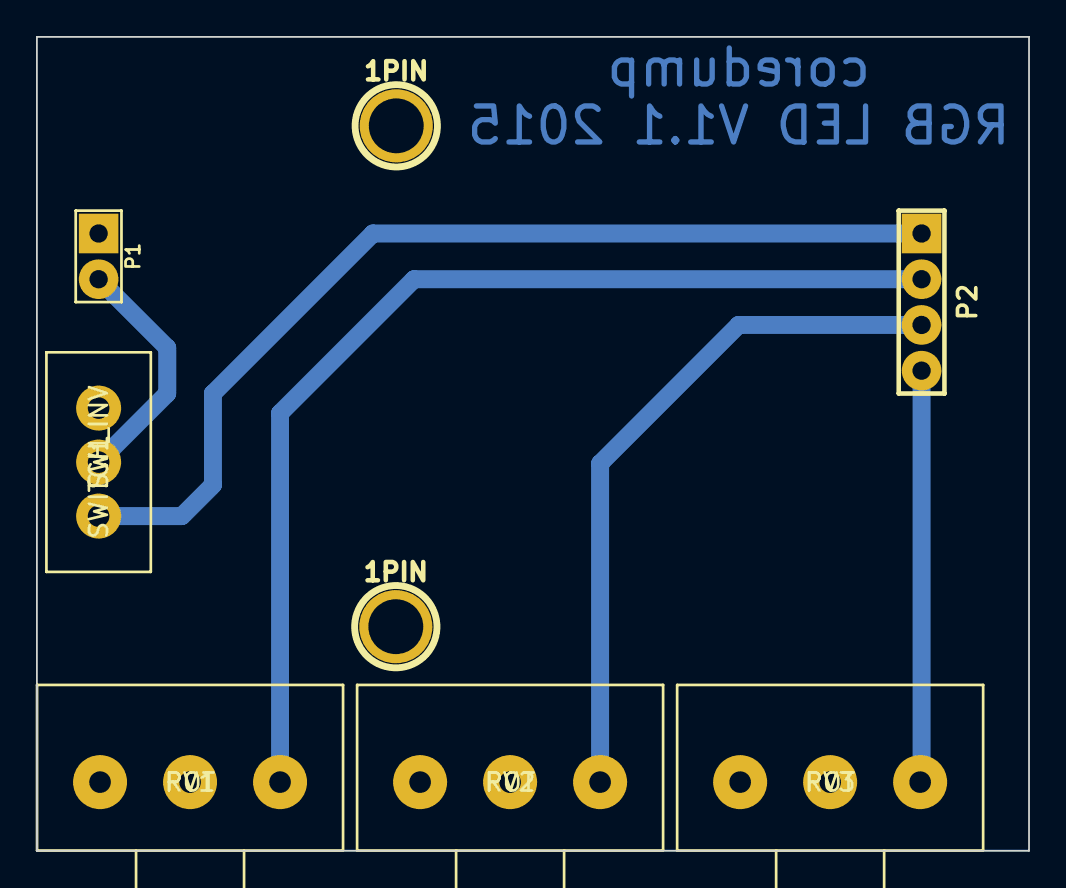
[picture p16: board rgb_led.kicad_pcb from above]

Board: 2 copper layers, 55.1 x 45.2 mm, 8 parts (0 on the bottom side), 6 nets.

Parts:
1PIN, 1PIN#2: P***; 1pin
P1: CONN_2; PIN_ARRAY_2X1_THICK
P2: CONN_4; PIN_ARRAY_4x1_THICK
RV1, RV2, RV3: POT; POT_3_THICK
SW1: SWITCH_INV; Switch_SS-12F46

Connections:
GND: P1.1, RV1.1, RV1.2, RV2.1, RV2.2, RV3.1, RV3.2
unnamed: P2.4, RV3.3
unnamed: P2.3, RV2.3
unnamed: P2.2, RV1.3
unnamed: P2.1, SW1.1
VDD: P1.2, SW1.2

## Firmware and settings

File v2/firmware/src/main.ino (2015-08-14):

/**
 * Main entry point for RGB LED controller.
 *
 * Copyright (c) 2014--2015 Coredump Rapperswil
 *
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
 * THE SOFTWARE IS PROVIDED “AS IS”, WITHOUT WARRANTY OF ANY KIND, EXPRESS OR
 * IMPLIED, INCLUDING BUT NOT LIMITED TO THE WARRANTIES OF MERCHANTABILITY,
 * FITNESS FOR A PARTICULAR PURPOSE AND NONINFRINGEMENT. IN NO EVENT SHALL THE
 * AUTHORS OR COPYRIGHT HOLDERS BE LIABLE FOR ANY CLAIM, DAMAGES OR OTHER
 * LIABILITY, WHETHER IN AN ACTION OF CONTRACT, TORT OR OTHERWISE, ARISING
 * FROM, OUT OF OR IN CONNECTION WITH THE SOFTWARE OR THE USE OR OTHER DEALINGS
 * IN THE SOFTWARE.
 */

// Get pin definitions
#include "pins.h"

// Include effects
#include "effects/colorwheel.h"
#include "effects/rgb_control.h"


// List of available effects
enum Effect {
    Colorwheel,
    RGBControl,
};

// Choose your effect
static const Effect effect = Colorwheel;


// Initialize GPIO pins
void setup() {
    // Set LED pins as output
    pinMode(LED_R, OUTPUT);
    pinMode(LED_G, OUTPUT);
    pinMode(LED_B, OUTPUT);

    // Set pot pins as input
    pinMode(POT_1, INPUT);
    pinMode(POT_2, INPUT);
    pinMode(POT_3, INPUT);
}


// Main loop
void loop() {

    switch (effect) {
        case Colorwheel:
            effect_colorwheel(); 
            break;
        case RGBControl:
            effect_rgb_control(); 
            break;
    }

}

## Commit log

2014-10-21 Added pcb design
    [rgb_led.kicad_pcb, rgb_led.sch, rgb_led_theorie.sch]
2014-10-21 Added potentiometer knobs
    [knob-b.stl, knob-g.stl, knob-r.stl]
2014-10-21 Smaller page config for schema
    [rgb_led.sch]
2014-10-21 Added potknob sources
    [knob.scad, textgenerator.scad]
2014-10-30 Added v2.0
    [rgb-led.fzz]
2014-10-30 Version 2.1
    [rgb-led.fzz]
2014-10-30 Version 2.2
    [rgb-led.fzz]
2014-11-01 Small tweaks on v2 project
    [rgb-led.fzz]
2014-11-27 Moved around folders
    [rgb_led.kicad_pcb, rgb_led.sch, rgb_led_theorie.sch]
2014-11-27 Started kicad version of v2
    [rgb-led-v2.sch, rgb-led.fzz]
2014-11-27 Continued work on v2
    [rgb-led-v2.sch, rgb-led.fzz]
2014-11-29 [library] Added IRF520 FET and KCD3 Switch
2014-11-29 [v2] Finished netlist assignment
    [rgb-led-v2.sch]
2014-11-29 [v2] Started work on PCB layout
    [rgb-led-v2.kicad_pcb, rgb-led-v2.sch]
2014-11-30 [v2] Fixed references in PCB layout
    [rgb-led-v2.kicad_pcb]
2014-11-30 [v2] Configured track widths
    [rgb-led-v2.kicad_pcb, rgb-led-v2.sch]
2014-11-30 [v2] Added fuse
    [rgb-led-v2.kicad_pcb, rgb-led-v2.sch]
2014-11-30 [v2] Added 3d version of irf520n
    [irf520n.fixed.stl, irf520n.scad, irf520n.stl]
2014-11-30 [v2] PCB Routing
    [rgb-led-v2.kicad_pcb, rgb-led-v2.sch]
2014-12-01 [v2] Improved PCB
    [rgb-led-v2.kicad_pcb]
2014-12-01 [v2] Removed outline of pot
    [rgb-led-v2.kicad_pcb]
2014-12-01 [v2] Added Gerber version
    [rgb-led-v2.GBL, rgb-led-v2.GBO, rgb-led-v2.GBS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]
2014-12-01 [v2] Removed old Fritzing project
    [rgb-led-v2.kicad_pcb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]
2014-12-01 [v2] Exported PNG files
    [rgb-led-v2.GBL, rgb-led-v2.GBO, rgb-led-v2.GBS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]
2015-02-11 [v2] Moved PCB files to subdirectory
    [rgb-led-v2.kicad_pcb, rgb-led-v2.sch]
2015-02-11 [v2] Fixed kicad library path
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2015-02-11 [v2] Created version 2.1
    [rgb-led-v2.kicad_pcb, rgb-led-v2.sch]
2015-08-14 [v2] Fixed Arduino makefile
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2015-08-14 [v2] rgb_control: Fix reading of the third poti
    [rgb_control.cpp]
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2015-08-14 [v2]: blue_sin: Fix calculation of val_b
    [blue_sin.cpp]
2015-08-15 [v2] rgb_control: Scale poti inputs correctly
    The potis are mounted in a way that makes them intuitively inverted. So
    we adjust it in the code.
    [rgb_control.cpp]
2015-08-15 [v2] Make it arduino IDE compatible
    Arduino needs to have the main entry file named the same like to folder
    it resides. Also it needs everything in a flat structure.
2015-08-19 add comments about range mapping and some brackets
2015-09-22 Fixed library path in v1 pcb
2015-09-22 v1: Add Switch to schematic
    [rgb_led.sch]
2015-09-22 library: Add footprint for SS-12F46 switch
    See http://mikroshop.ch/Zubehoer.html?gruppe=10&artikel=483
2015-09-22 v1: Add switch to PCB and make it a bit smaller
    [rgb_led.kicad_pcb]
2015-09-23 [v1] Adjusted date and version on PCB
    [rgb_led.kicad_pcb]
2015-09-23 Increased distance between battery holes
    9V battery length is 26.5mm.
    [rgb_led.kicad_pcb]
2015-09-24 Made board smaller
    [rgb_led.kicad_pcb]
2015-09-24 Changed color labels to letters only
    [rgb_led.kicad_pcb]
2015-09-24 Added OSHW logo
    [rgb_led.kicad_pcb]
2015-09-24 Fixed edge cut
    [rgb_led.kicad_pcb]
2015-09-24 Changed footprint page size to A4
    [rgb_led.kicad_pcb]
2015-09-24 Actually fixed edge cuts
    [rgb_led.kicad_pcb]
2015-09-24 Straightened fill zone
    [rgb_led.kicad_pcb]
2015-09-24 Increased font size for pot labels
    [rgb_led.kicad_pcb]
2015-09-24 Updated ground plane
    - Moved all text and image content to the copper layer
    - Added a zone cutout for the top part
    [rgb_led.kicad_pcb]
2015-09-24 Made footprints thicker
    [rgb_led.kicad_pcb]
2015-09-24 Made border a bit nicer
    [rgb_led.kicad_pcb]
2015-10-05 Added newer version of pot knobs
    [knob-b-v2.stl, knob-g-v2.stl, knob-r-v2.stl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]
2016-08-13 Update pcb-v2.1 to kicad4
    I just opened the project with kicad4 and it needed to change some
    components and I needed to remove the "special" library. Also kicad
    created a "rescue" library.
    [rgb-led-v2.sch]
2016-08-24 Open project again and save it
    At this point I'm a bit confused about what KiCad is doing exactly...
    [rgb-led-v2.sch]
2016-08-29 Add KiCad cache library
    The cache library contains all parts used in the schematic and PCB. If
    we want to make sure we are able to open the project across library
    versions on different machines we need to add it.
2016-08-30 Fixed power flags to make ERC happy
    [rgb-led-v2.sch]
2016-09-04 PCB: Remove unnecessary vias
    [rgb-led-v2.kicad_pcb]
2016-09-04 Make pads for switch bigger
    Fixes #7
    [rgb-led-v2.kicad_pcb]
2016-09-15 Add DC jack
    Fixes #1
    [rgb-led-v2.kicad_pcb, rgb-led-v2.sch]
2016-09-19 Move open hardware logo and improve spacing
    [rgb-led-v2.kicad_pcb]
2016-09-19 Update metadata and text label
    [rgb-led-v2.kicad_pcb, rgb-led-v2.sch]
2016-09-19 Add mounting holes
    [rgb-led-v2.kicad_pcb]
2016-10-14 Replace tabs with 2 spaces
    [knob.scad]
2016-10-14 Knob v3
    [knob-b-v3.stl, knob-g-v3.stl, knob-neutral-v3.stl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]
2017-02-19 Add v2.2
    [rgb-led-v2.kicad_pcb, rgb-led-v2.sch]
2017-02-19 Add another mounting hole
    [rgb-led-v2.kicad_pcb]
2017-02-19 3D paths
    [rgb-led-v2.kicad_pcb]
2017-02-19 Improved routing, thinner traces
    [rgb-led-v2.kicad_pcb]
2017-02-19 Add pin headers to schema
    [rgb-led-v2.sch]
2017-02-19 Add pin headers to Arduino
    [rgb-led-v2.kicad_pcb]
2017-02-19 Add pin headers to PCB
    [rgb-led-v2.kicad_pcb]
2017-02-19 Made switch holes a bit wider again
    [rgb-led-v2.kicad_pcb]
2017-02-19 Two push buttons (fixes #2)
    [rgb-led-v2.kicad_pcb, rgb-led-v2.sch]
2017-02-19 More spacing between pin headers and Arduino
    [rgb-led-v2.kicad_pcb]
2017-02-20 Add gerber output for v2.1
    [rgbled.GBL, rgbled.GBO, rgbled.GBS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]
2017-02-20 Align resistors
    [rgb-led-v2.kicad_pcb]
2017-02-20 More resistor alignment
    [rgb-led-v2.kicad_pcb]
